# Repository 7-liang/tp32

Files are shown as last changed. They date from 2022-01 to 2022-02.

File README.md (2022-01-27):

# TP32
## Tp32 keyboard with running QMK

---

### IMG
[images](img/)

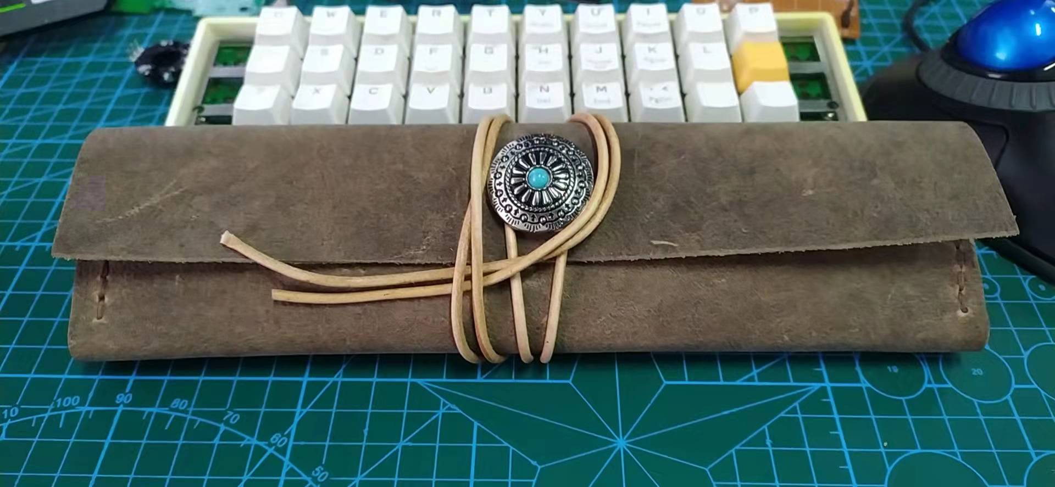
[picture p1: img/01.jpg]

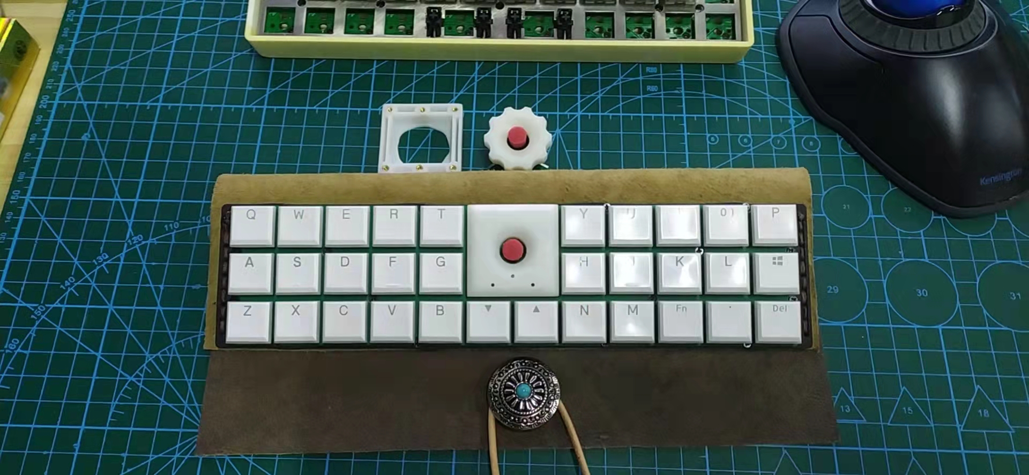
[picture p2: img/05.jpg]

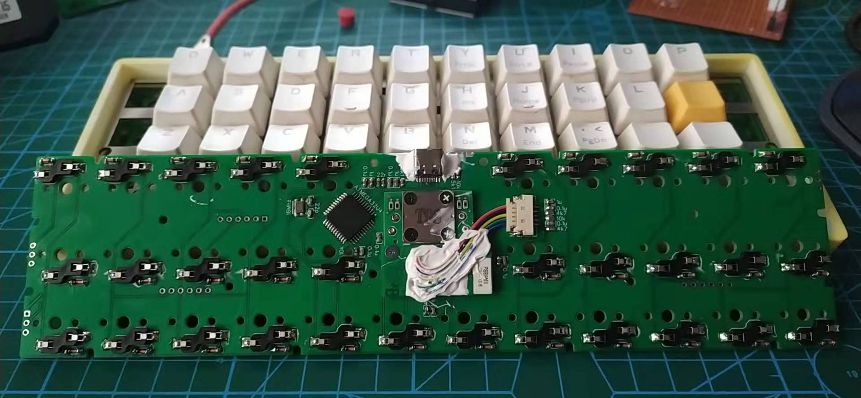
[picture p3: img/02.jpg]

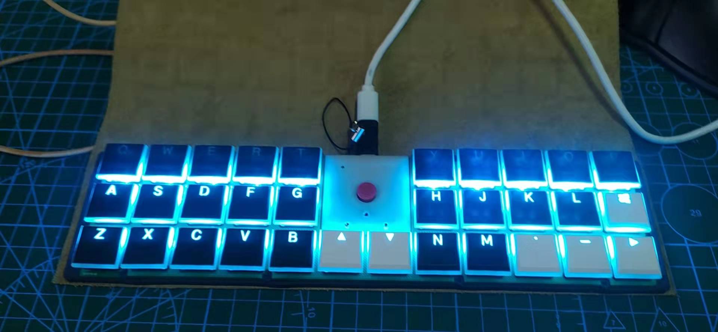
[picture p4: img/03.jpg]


### TrackPoint

for thinkpad t400 r400 t500 r500 .......

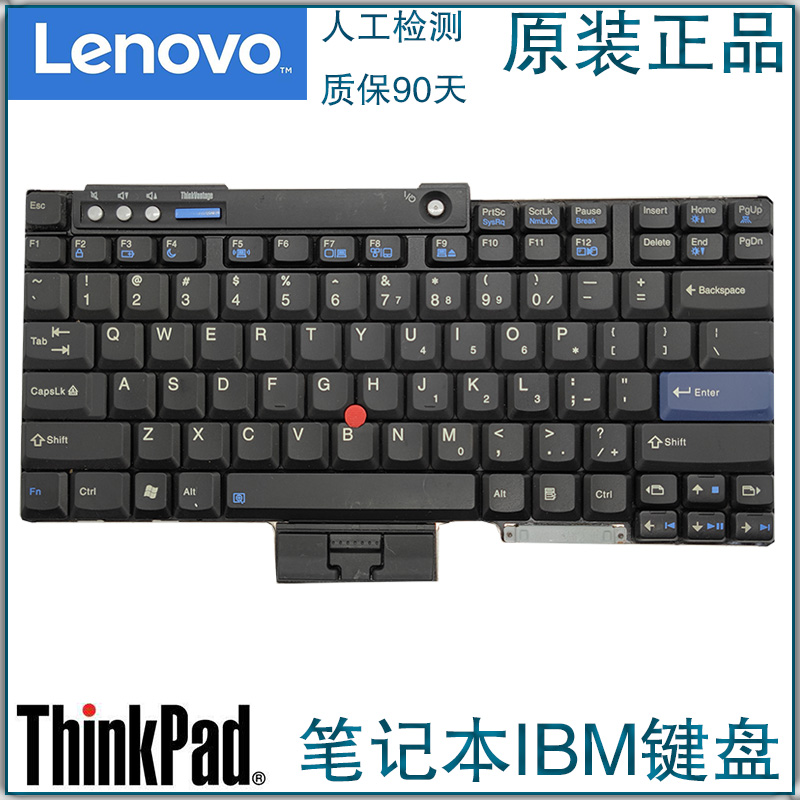
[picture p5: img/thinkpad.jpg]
thinkpad

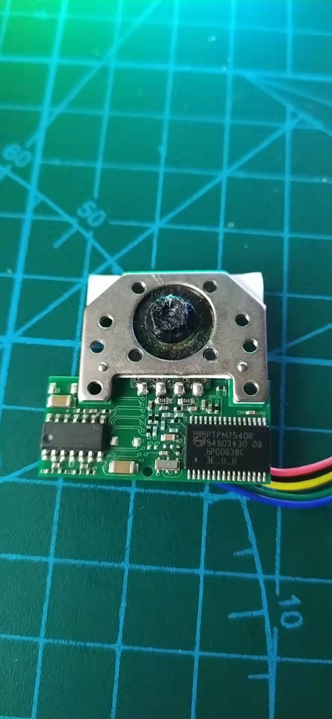
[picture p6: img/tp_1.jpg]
tp_1

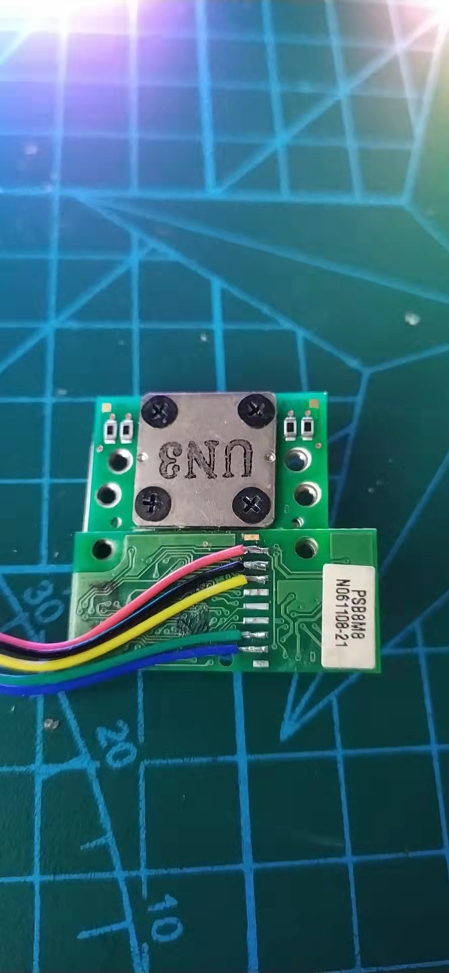
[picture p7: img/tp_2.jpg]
tp_2


line    | pad
--------|----------
red     | vcc
black   | gnd
yellow  | clk
green   | rst
blue    | data

### PCB

[gerber](gerber/)

[sch](sch/)

[OSHW](https://oshwhub.com/pkerr/keyborard-juk-32-rev-a)

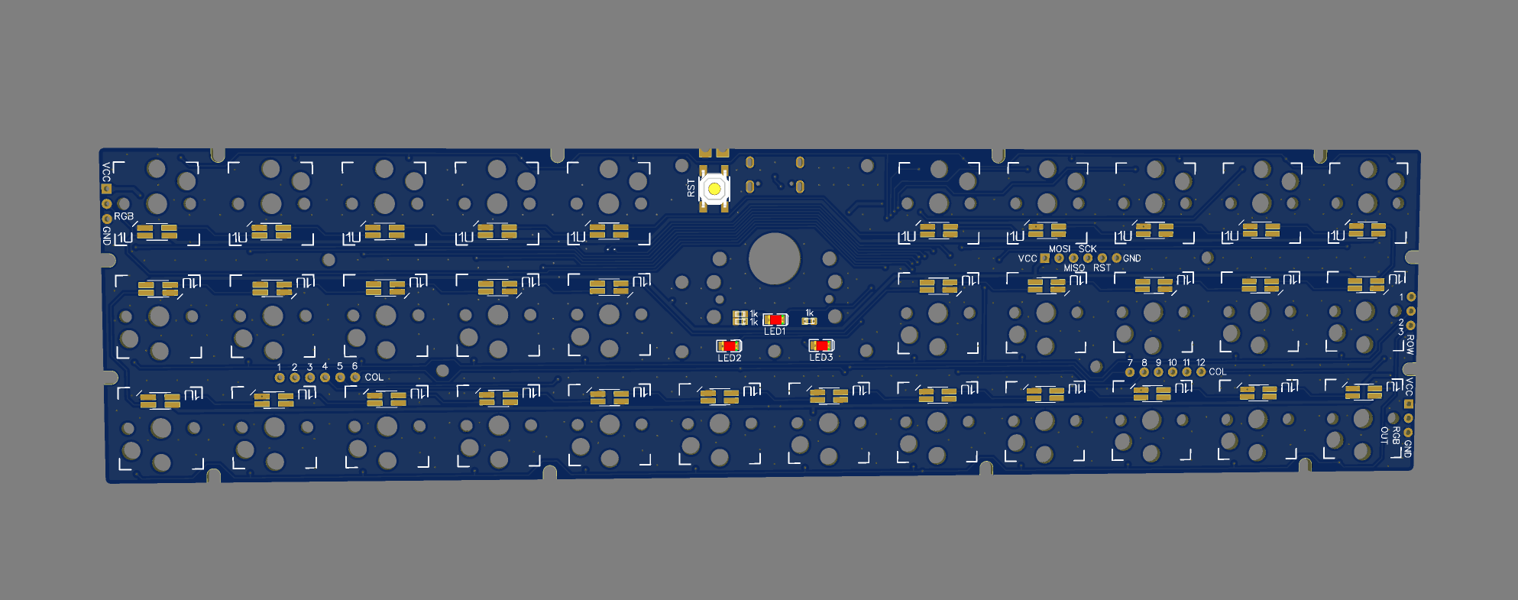
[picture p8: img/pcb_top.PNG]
pcb_top

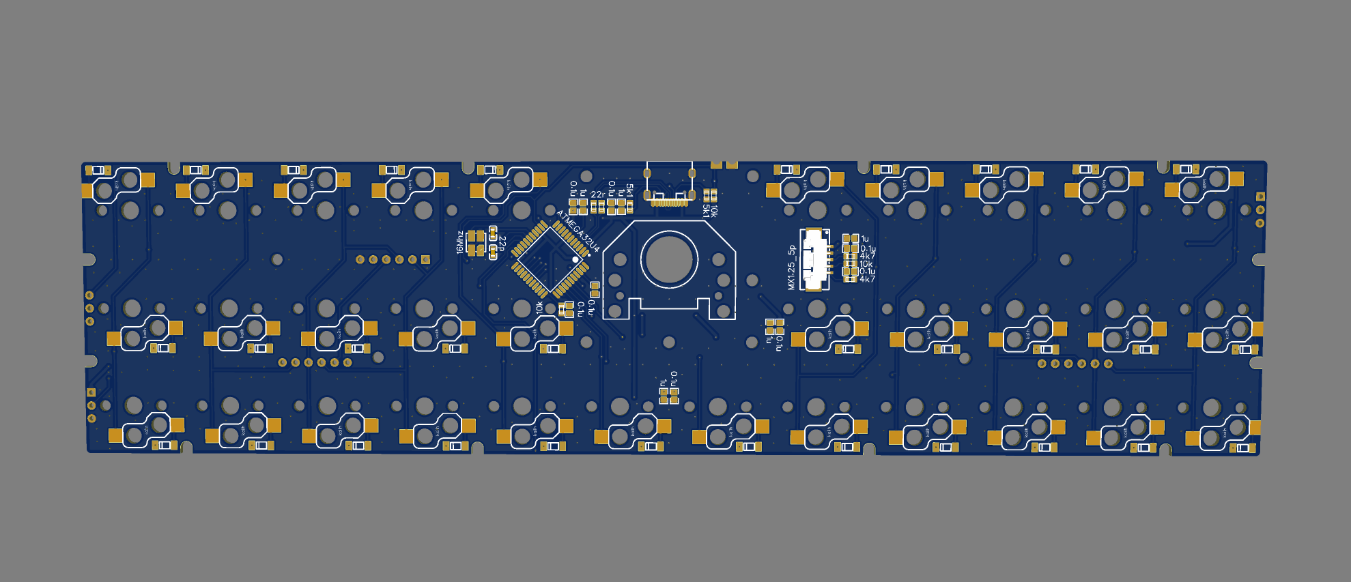
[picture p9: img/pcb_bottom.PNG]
pcb_bottom


### 3D files

[stl](stl/)

[solidworks](sw/)

### qmk

[code](code/)

### bom

Part            | Value     | Quantity
----------------|-----------|-----------
atmega32u4      | au        | 1
trackpoint      |           | 1
ws2812b         | 3528      | 32
1n4148          |           | 32
kaihua choc     |           | 32
usb-c           | 16p       | 1
max 1.25        | smd       | 1
crystal 3225    | 16Mhz     | 1
c 0603          | 22p       | 2
c 0603          | 0.1u      | 8
c 0603          | 1u        | 5
r 0603          | 22        | 2
r 0603          | 1k        | 3
r 0603          | 4k7       | 2
r 0603          | 5k1       | 2
r 0603          | 10k       | 3
sw 4x4          |           | 0 or 1

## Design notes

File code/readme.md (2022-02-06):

# Tp32

tp32

tp32

tp32

tp32

this is trackpoint 32 keys keyboard

* Keyboard Maintainer: [skyjun](https://github.com/skyjun/tp32)
* Hardware Supported: pcb, 3d files, thinkpad trackpoint
* Hardware Availability: [gerber](https://github.com/skyjun/tp32/tree/main/gerber), [stl](https://github.com/skyjun/tp32/tree/main/stl), [at OSHWHUB](https://oshwhub.com/pkerr/keyborard-juk-32-rev-a)

Make example for this keyboard (after setting up your build environment):

    make 7liang/tp32:default

See the [build environment setup](https://docs.qmk.fm/#/getting_started_build_tools) and the [make instructions](https://docs.qmk.fm/#/getting_started_make_guide) for more information. Brand new to QMK? Start with our [Complete Newbs Guide](https://docs.qmk.fm/#/newbs).

## Bootloader

Enter the bootloader in 3 ways:

* **Bootmagic reset**: Hold down the key at (0,0) in the matrix (usually the top left key or Escape) and plug in the keyboard
* **Physical reset button**: Briefly press the button on the top of the PCB, or the reset pads at the edge of the short
* **Keycode in layout**: Press the key mapped to `RESET` if it is available

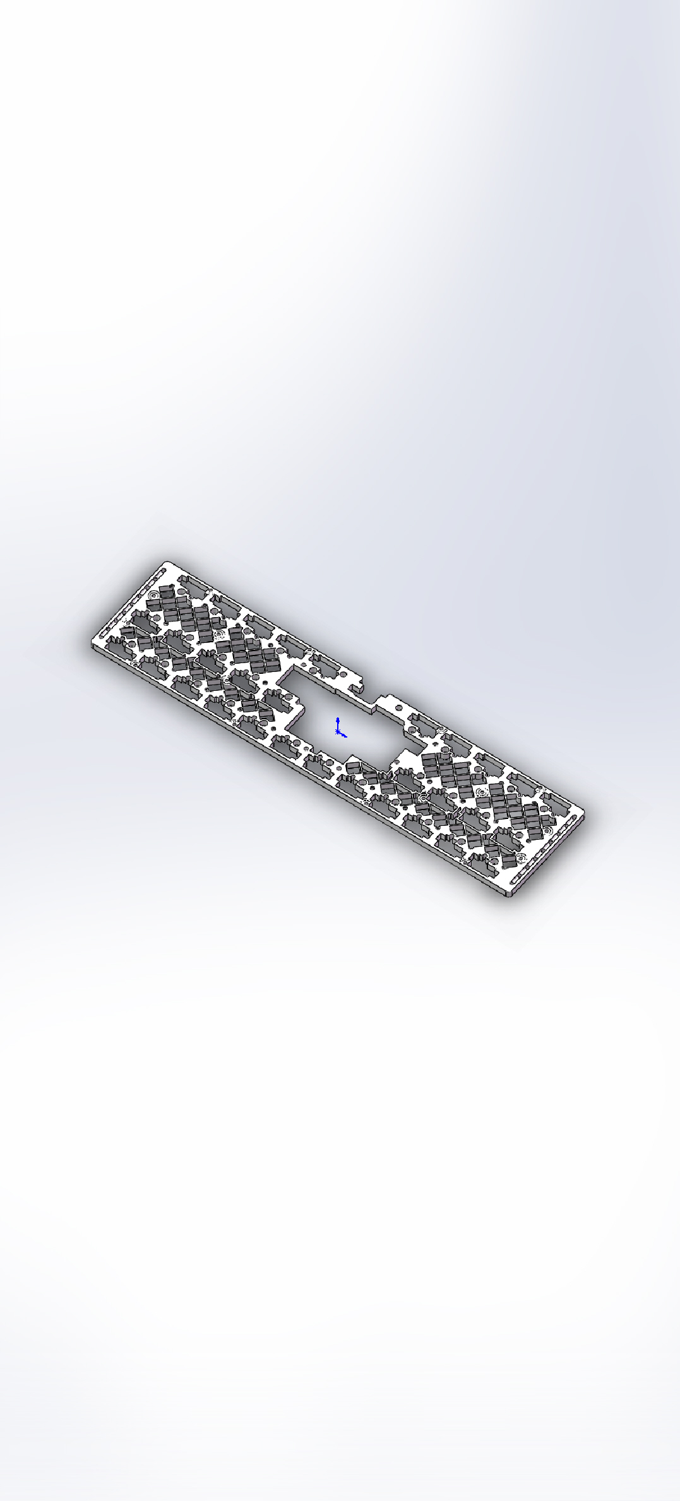
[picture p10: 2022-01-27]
img/floor.JPG

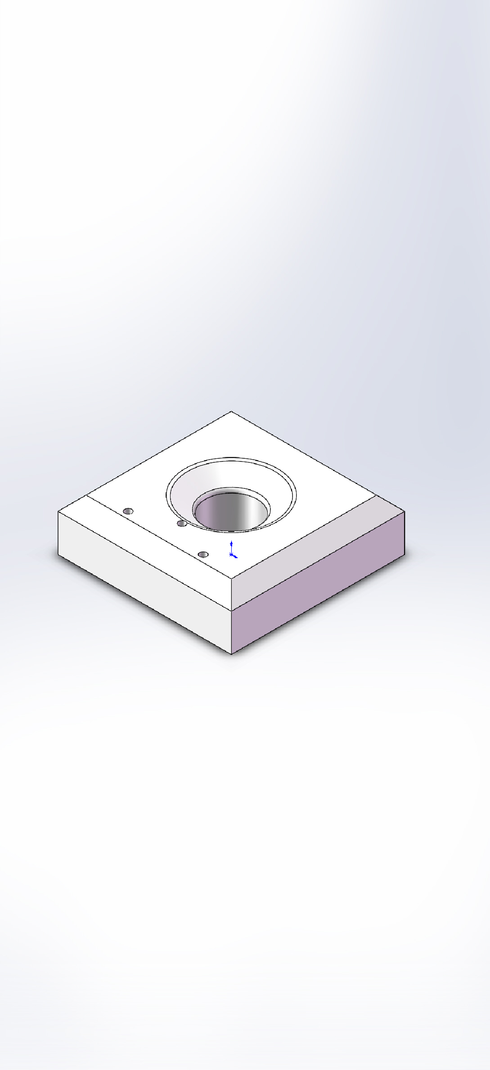
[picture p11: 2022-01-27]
img/tp_lid.JPG

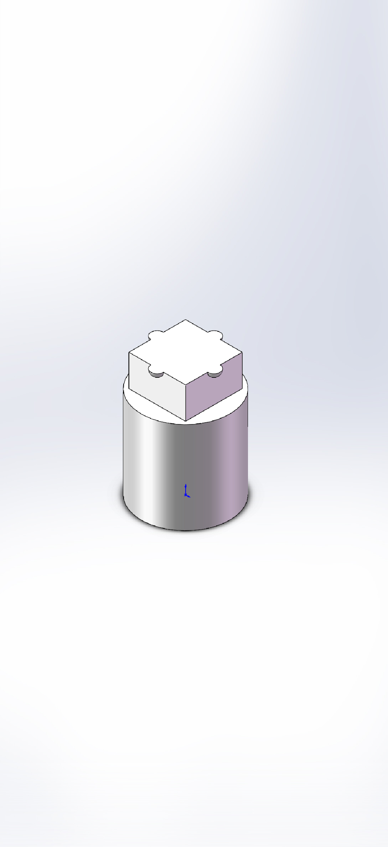
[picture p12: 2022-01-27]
img/rod.JPG

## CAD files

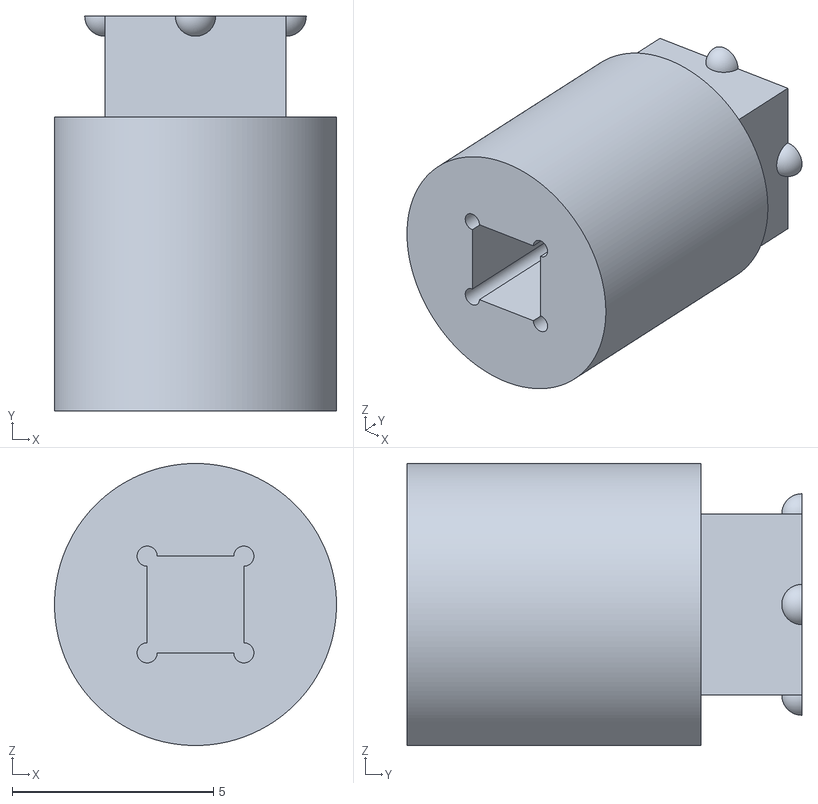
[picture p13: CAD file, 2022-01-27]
stl/rod_2.STL
7.00 x 9.80 x 7.00

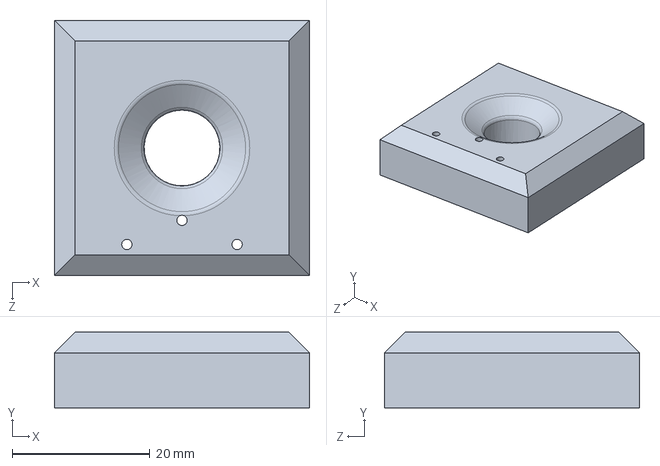
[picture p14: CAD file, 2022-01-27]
sw/tp_lid.SLDPRT
37.0 x 11.0 x 37.0 mm

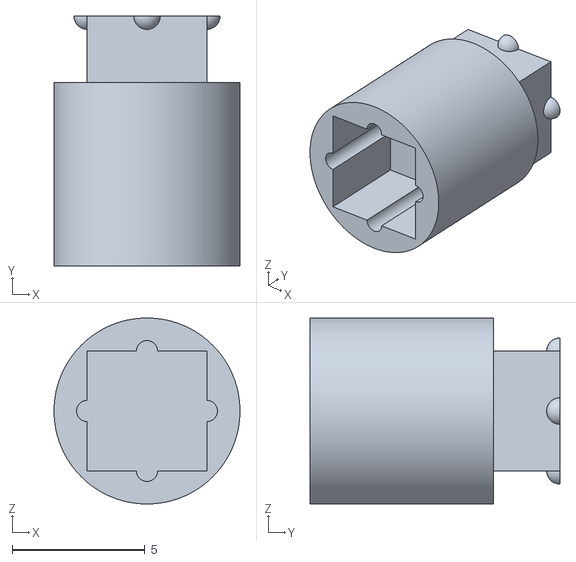
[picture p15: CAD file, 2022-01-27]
stl/rod_1.STL
7.00 x 9.40 x 7.00

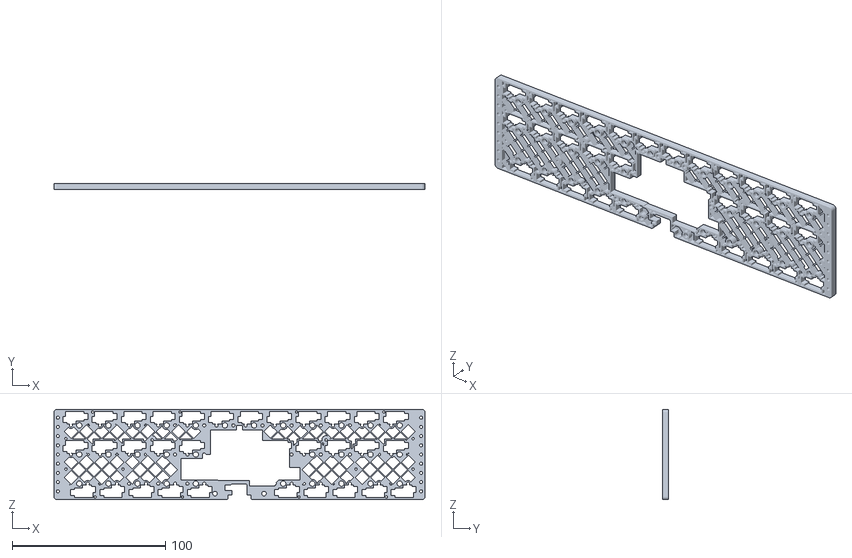
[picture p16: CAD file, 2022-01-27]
stl/floor.STL
242.0 x 4.00 x 59.0

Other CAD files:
stl/tp_lid.STL
sw/rod_2.SLDPRT
sw/rod_1.SLDPRT

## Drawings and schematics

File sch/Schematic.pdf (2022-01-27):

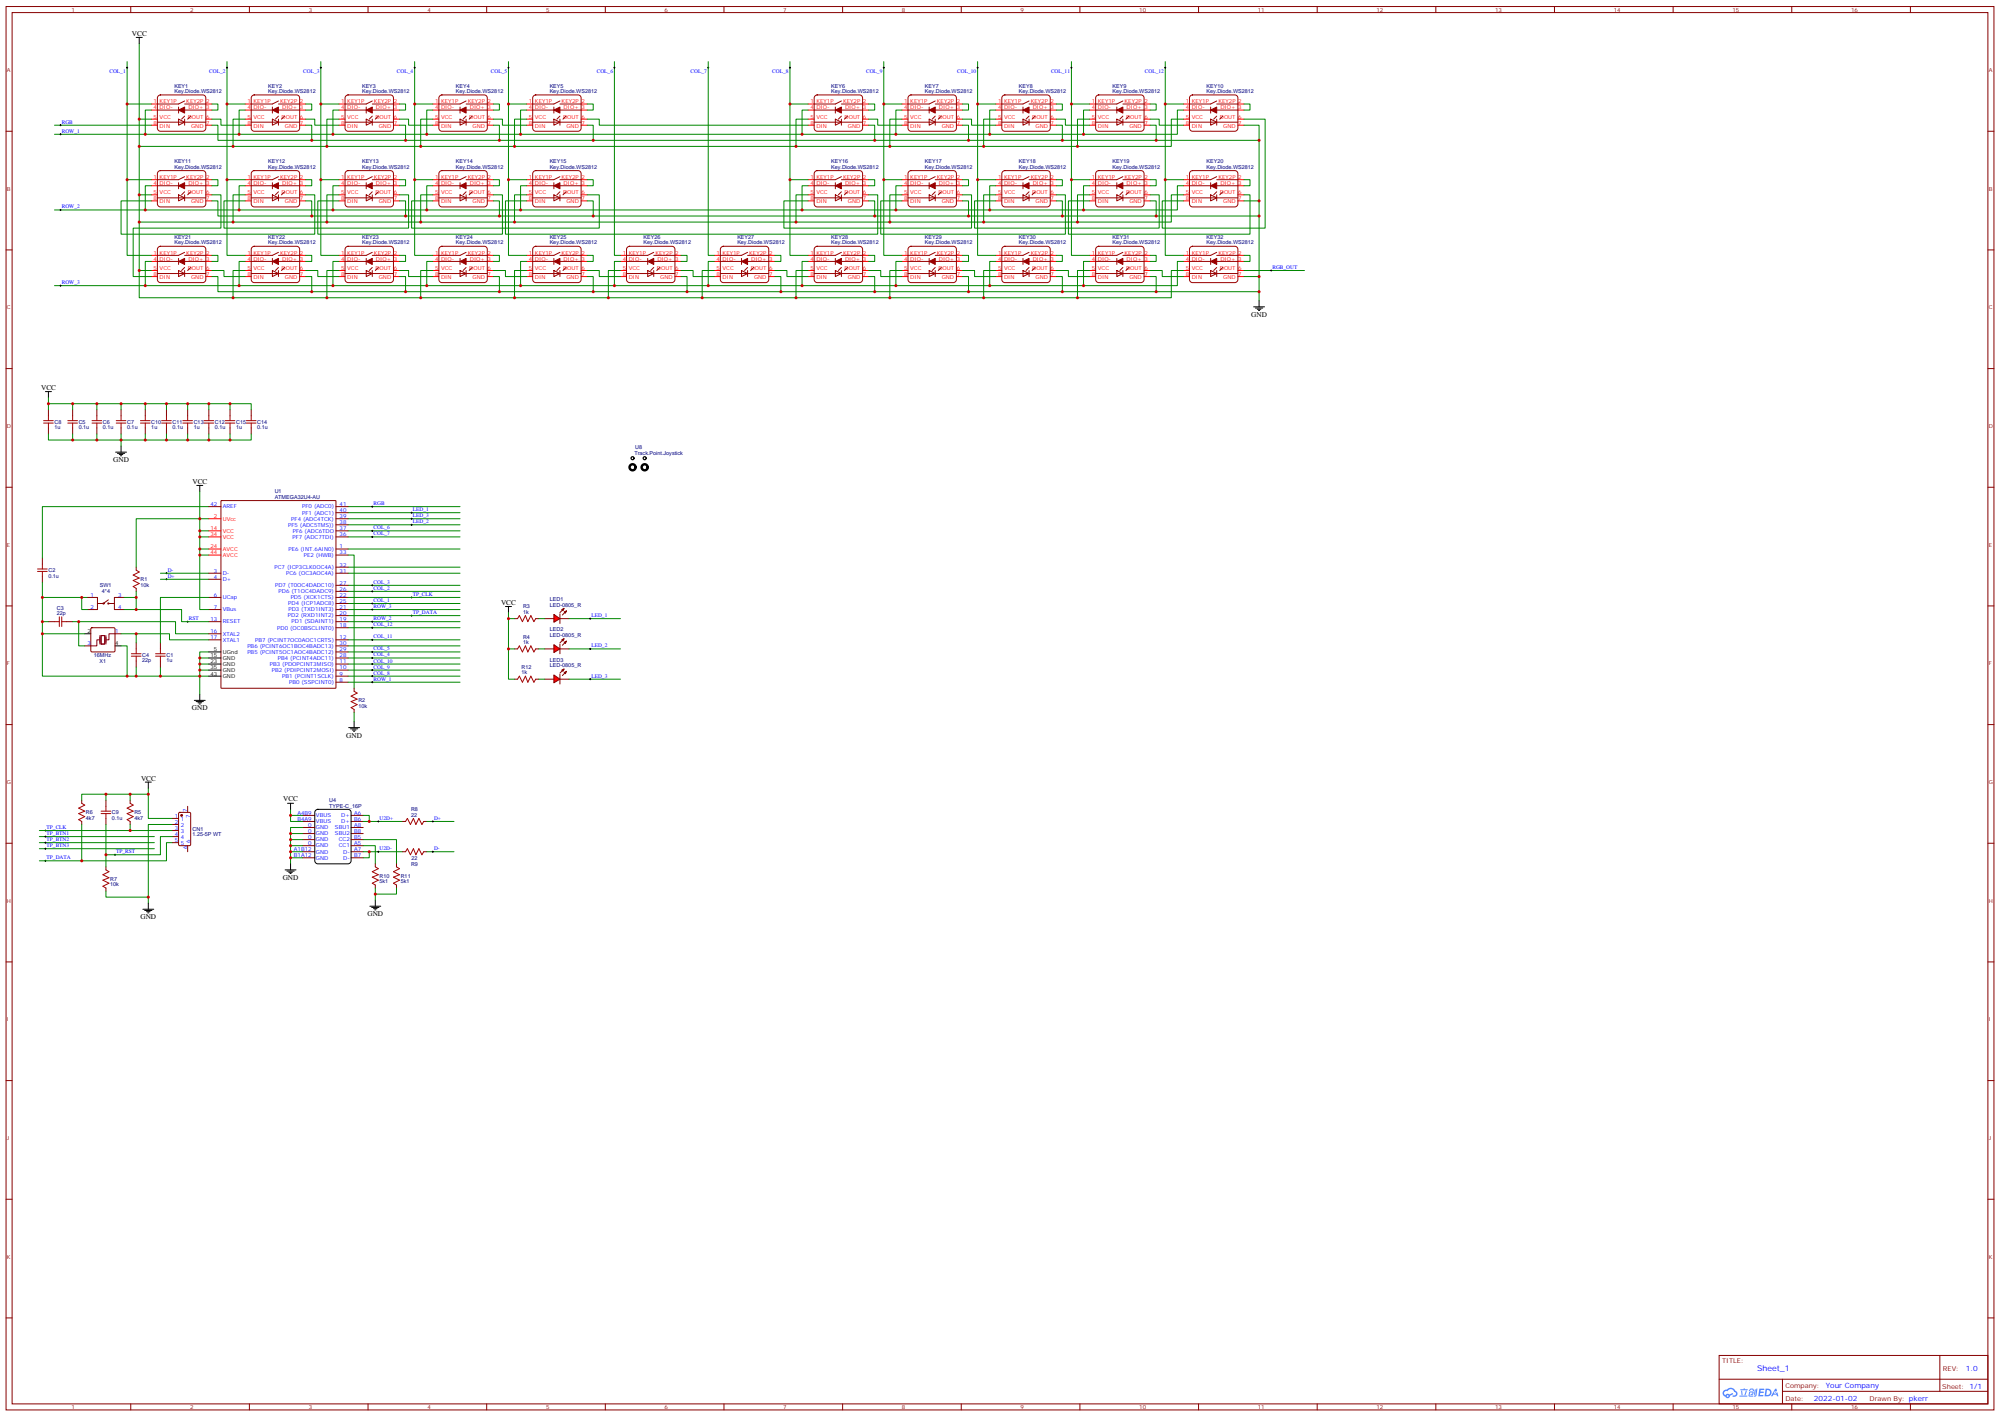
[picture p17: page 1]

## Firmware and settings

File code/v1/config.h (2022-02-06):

/* Copyright 2022 SevenLiang(@skyjun)
 *
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
 * You should have received a copy of the GNU General Public License
 * along with this program.  If not, see <http://www.gnu.org/licenses/>.
 */

#pragma once

#define PRODUCT_ID   0x0001
#define DEVICE_VER   0x0001

#define MATRIX_ROW_PINS { B0, D1, D3 }
#define MATRIX_COL_PINS { D4, D6, D7, B4, B5, F6, F7, B1, B2, B3, B7, D0 }
#define UNUSED_PINS

#define DIODE_DIRECTION COL2ROW

#define DEBOUNCE 5

#define LOCKING_SUPPORT_ENABLE
#define LOCKING_RESYNC_ENABLE

#define NO_ACTION_MACRO
#define NO_ACTION_FUNCTION

#define RGB_DI_PIN          F0
#define RGBLED_NUM          32

// animations enable
#define RGBLIGHT_EFFECT_BREATHING
#define RGBLIGHT_EFFECT_RAINBOW_MOOD
#define RGBLIGHT_EFFECT_RAINBOW_SWIRL
#define RGBLIGHT_EFFECT_SNAKE
#define RGBLIGHT_EFFECT_KNIGHT
#define RGBLIGHT_EFFECT_CHRISTMAS
#define RGBLIGHT_EFFECT_STATIC_GRADIENT
#define RGBLIGHT_EFFECT_RGB_TEST
#define RGBLIGHT_EFFECT_ALTERNATING
#define RGBLIGHT_EFFECT_TWINKLE

#define RGBLIGHT_SLEEP

#define LED_CAPS_LOCK_PIN   F5
#define LED_NUM_LOCK_PIN    F4
// 按键灯，按下任意键都会亮一下
// press any key will turn on the light diode
#define LED_KEY_PRESS_PIN   F1

// trackpoint pin
#define PS2_CLOCK_PIN   D5
#define PS2_DATA_PIN    D2

// UART 方式
#ifdef PS2_USE_USART
#define PS2_USART_INIT() do {                   \
    PS2_CLOCK_DDR   &= ~(1 << PS2_CLOCK_BIT);   \
    PS2_DATA_DDR    &= ~(1 << PS2_DATA_BIT);    \
    UCSR1C          = ((1 << UMSEL10) |         \
                        (3 << UPM10) |          \
                        (0 << USBS1) |          \
                        (3 << UCSZ10) |         \
                        (0 << UCPOL1));         \
    UCSR1A          = 0;                        \
    UBRR1H          = 0;                        \
    UBRR1L          = 0;                        \
} while (0)
#define PS2_USART_RX_INT_ON() do {              \
    UCSR1B          = ((1 << RXCIE1) |          \
                        (1 << RXEN1));          \
} while (0)
#define PS2_USART_RX_POLL_ON() do {             \
    UCSR1B          = (1 << RXEN1);             \
} while (0)
#define PS2_USART_OFF() do {                    \
    UCSR1C          = 0;                        \
    UCSR1B          &= ~((1 << RXEN1) |         \
                        (1 << TXEN1));          \
} while (0)
#define PS2_USART_RX_READY      (UCSR1A & (1 << RXC1))
#define PS2_USART_RX_DATA       UDR1
#define PS2_USART_ERROR         (UCSR1A & ((1 << FE1) | (1 << DOR1) | (1 << UPE1)))
#define PS2_USART_RX_VECT       USART1_RX_vect
#endif

// 中断方式
#ifdef PS2_USE_INT
#define PS2_INT_INIT() do {                     \
    EICRA           |= ((1 << ISC21) |          \
                        (0 << ISC20));          \
} while (0)
#define PS2_INT_ON() do {                       \
    EIMSK           |= (1 << INT2);             \
} while (0)
#define PS2_INT_OFF() do {                      \
    EIMSK           &= ~(1 << INT2);            \
} while (0)
#define PS2_INT_VECT    INT2_vect
#endif

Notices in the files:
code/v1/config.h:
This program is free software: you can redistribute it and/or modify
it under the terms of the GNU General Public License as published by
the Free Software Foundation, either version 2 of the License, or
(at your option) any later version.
